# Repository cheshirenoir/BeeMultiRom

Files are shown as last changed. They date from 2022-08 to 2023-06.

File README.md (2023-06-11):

# BeeMultiRom
27c128 to 27c2001 adapter with selector for choosing between 16 different ROM images.
CC BY SA created in KiCAD
TESTED OK! If you use it in the IC22 socket of a PC85b, you can use double sized ROMs. If you use single sized ROMs, you can then access the lower ROM with PAK4 and the upper ROM with PAK12
This new version uses turned pins (from turned pin sockets. Just cut them mout with side cutters) and will just fit inside the case of a Microbee. 

Assembly instructions here: https://ilike8bits.com/assembling-the-microbee-multirom/

CC BY SA

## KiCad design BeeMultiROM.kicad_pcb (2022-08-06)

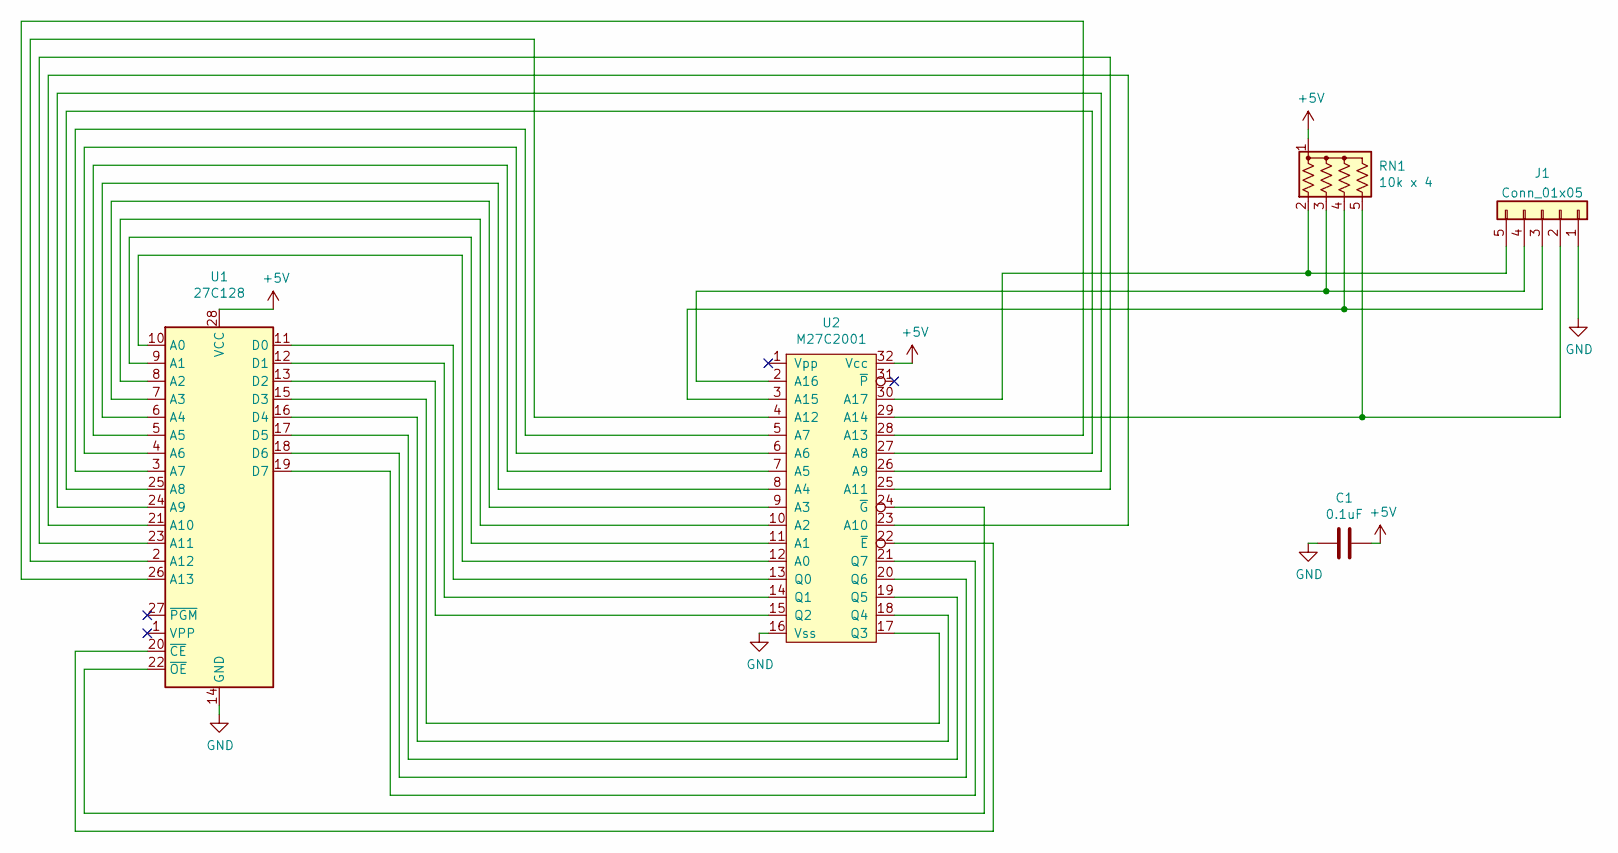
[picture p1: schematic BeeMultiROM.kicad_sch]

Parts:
C1: 0.1uF; C_Disc_D8.0mm_W2.5mm_P5.00mm
J1: Conn_01x05; PinHeader_1x05_P2.54mm_Vertical
RN1: 10k x 4; R_Array_SIP5
U1: 27C128; DIP-28_W15.24mm
U2: M27C2001; DIP-32_LP_FATBOY

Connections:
+5V: C1.1, RN1.1 (common), U1.28 (VCC), U2.32 (Vcc)
GND: C1.2, J1.1, U1.14 (GND), U2.16 (Vss)
unnamed: J1.2, RN1.5 (R4), U2.29 (A14)
unnamed: J1.3, RN1.4 (R3), U2.3 (A15)
unnamed: J1.4, RN1.3 (R2), U2.2 (A16)
unnamed: J1.5, RN1.2 (R1), U2.30 (A17)
unnamed: U1.2 (A12), U2.4 (A12)
unnamed: U1.3 (A7), U2.5 (A7)
unnamed: U1.4 (A6), U2.6 (A6)
unnamed: U1.5 (A5), U2.7 (A5)
unnamed: U1.6 (A4), U2.8 (A4)
unnamed: U1.7 (A3), U2.9 (A3)
unnamed: U1.8 (A2), U2.10 (A2)
unnamed: U1.9 (A1), U2.11 (A1)
unnamed: U1.10 (A0), U2.12 (A0)
unnamed: U1.11 (D0), U2.13 (Q0)
unnamed: U1.12 (D1), U2.14 (Q1)
unnamed: U1.13 (D2), U2.15 (Q2)
unnamed: U1.15 (D3), U2.17 (Q3)
unnamed: U1.16 (D4), U2.18 (Q4)
unnamed: U1.17 (D5), U2.19 (Q5)
unnamed: U1.18 (D6), U2.20 (Q6)
unnamed: U1.19 (D7), U2.21 (Q7)
unnamed: U1.20 (~CE), U2.22 (~E)
unnamed: U1.21 (A10), U2.23 (A10)
unnamed: U1.22 (~OE), U2.24 (~G)
unnamed: U1.23 (A11), U2.25 (A11)
unnamed: U1.24 (A9), U2.26 (A9)
unnamed: U1.25 (A8), U2.27 (A8)
unnamed: U1.26 (A13), U2.28 (A13)

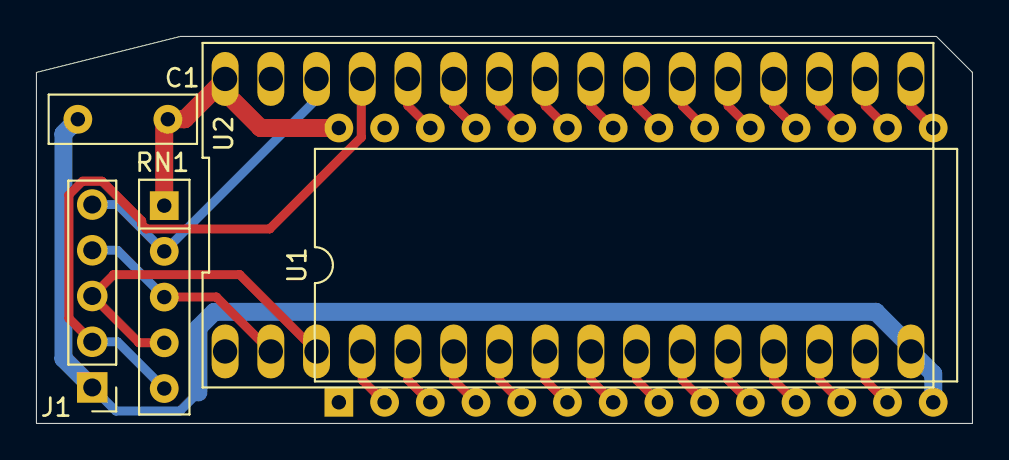
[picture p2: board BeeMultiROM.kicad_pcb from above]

Board: 2 copper layers, 52.0 x 21.5 mm, 5 parts (0 on the bottom side), 30 nets.

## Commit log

2021-12-12 Add files via upload
    Initial version. CC BY SA
    [BeeMultiROM.kicad_pcb, BeeMultiROM.sch]
2022-03-18 Add files via upload
    Gerbers of the BeeMultiRom, successfully tested
    [BeeMultiROM-B_Cu.gbl, BeeMultiROM-B_Mask.gbs, BeeMultiROM-B_Paste.gbp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]
2022-08-06 Add files via upload
    Super low profile version
    [BeeMultiROM.kicad_pcb, BeeMultiROM.kicad_sch]

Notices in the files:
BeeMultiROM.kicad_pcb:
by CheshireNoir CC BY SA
